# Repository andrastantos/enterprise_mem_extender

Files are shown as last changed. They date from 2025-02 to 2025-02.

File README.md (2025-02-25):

A 512kB RAM expansion design for the Enterprise computer
===================================================================

This design can be used to add up to 512kB of RAM without to an Enterprise computer.
Jumpers can be used to determine the amount of RAM added (64k, 128k, 256k or 512k).

You can read up on whole project in detail here: https://www.modularcircuits.com/blog/2025/02/25/enterprise-128-a-blast-from-the-past/

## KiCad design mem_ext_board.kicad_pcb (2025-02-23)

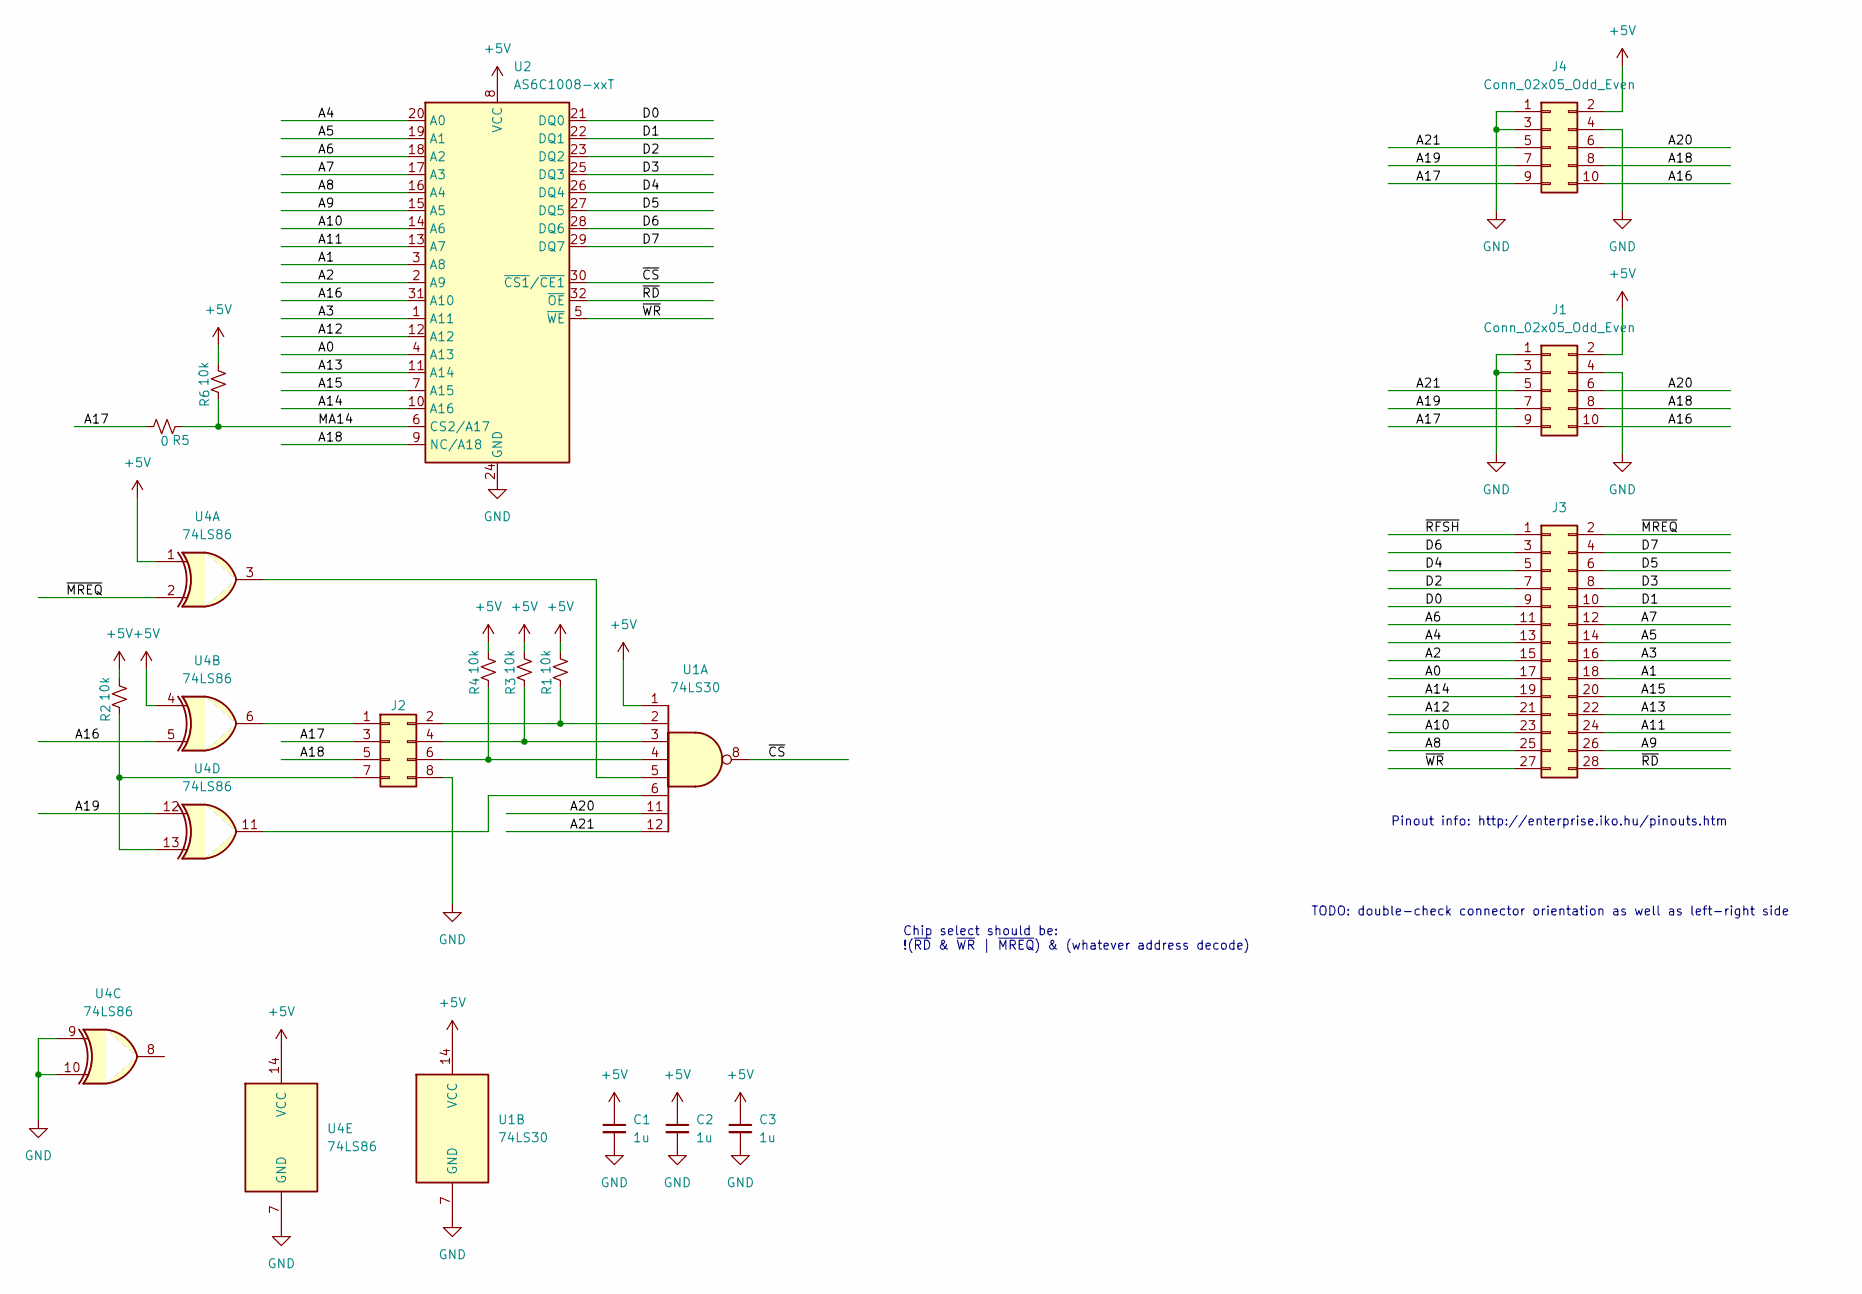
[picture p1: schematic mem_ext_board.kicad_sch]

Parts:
C1, C2, C3: 1u; C_0603_1608Metric_Pad1.08x0.95mm_HandSolder
J1: Conn_02x05_Odd_Even; PinHeader_2x05_P2.54mm_Vertical
J2: Conn_02x02_Odd_Even; PinHeader_2x04_P2.54mm_Vertical
J3: Conn_02x16_Row_Letter_First; PinSocket_2x14_P2.54mm_Vertical
J4: Conn_02x05_Odd_Even; PinSocket_2x05_P2.54mm_Vertical
R1, R2, R3, R4, R6: 10k; R_0603_1608Metric_Pad0.98x0.95mm_HandSolder
R5: 0; R_0603_1608Metric_Pad0.98x0.95mm_HandSolder
U1: 74LS30; SO-14_3.9x8.65mm_P1.27mm; mpn CD74HCT30M
U2: AS6C1008-xxT; TSOP-I-32_11-18.4x8mm_P0.5mm
U4: 74LS86; SO-14_3.9x8.65mm_P1.27mm; mpn CD74HCT86D

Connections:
+5V: C1.1, C2.1, C3.1, J1.2, J4.2, R1.1, R2.1, R3.1, R4.1, R6.1, U1.1, U1.14 (VCC), U2.8 (VCC), U4.1, U4.4, U4.14 (VCC)
/A0: J3.17, U2.4 (A13)
/A1: J3.18, U2.3 (A8)
/A2: J3.15, U2.2 (A9)
/A3: J3.16, U2.1 (A11)
/A4: J3.13, U2.20 (A0)
/A5: J3.14, U2.19 (A1)
/A6: J3.11, U2.18 (A2)
/A7: J3.12, U2.17 (A3)
/A8: J3.25, U2.16 (A4)
/A9: J3.26, U2.15 (A5)
/A10: J3.23, U2.14 (A6)
/A11: J3.24, U2.13 (A7)
/A12: J3.21, U2.12 (A12)
/A13: J3.22, U2.11 (A14)
/A14: J3.19, U2.10 (A16)
/A15: J3.20, U2.7 (A15)
/A16: J1.10, J4.10, U2.31 (A10), U4.5
/A17: J1.9, J2.3, J4.9, R5.1
/A18: J1.8, J2.5, J4.8, U2.9 (NC/A18)
/A19: J1.7, J4.7, U4.12
/A20: J1.6, J4.6, U1.11
/A21: J1.5, J4.5, U1.12
/D0: J3.9, U2.21 (DQ0)
/D1: J3.10, U2.22 (DQ1)
/D2: J3.7, U2.23 (DQ2)
/D3: J3.8, U2.25 (DQ3)
/D4: J3.5, U2.26 (DQ4)
/D5: J3.6, U2.27 (DQ5)
/D6: J3.3, U2.28 (DQ6)
/D7: J3.4, U2.29 (DQ7)
/MA14: R5.2, R6.2, U2.6 (CS2/A17)
/~CS: U1.8, U2.30 (~CS1/~CE1)
/~MREQ: J3.2, U4.2
/~RD: J3.28, U2.32 (~OE)
/~RFSH: J3.1
/~WR: J3.27, U2.5 (~WE)
GND: C1.2, C2.2, C3.2, J1.1, J1.3, J1.4, J2.8, J4.1, J4.3, J4.4, U1.7 (GND), U2.24 (GND), U4.7 (GND), U4.9, U4.10
unnamed: J2.1, U4.6
unnamed: J2.2, R1.2, U1.2
unnamed: J2.4, R3.2, U1.3
unnamed: J2.6, R4.2, U1.4
unnamed: J2.7, R2.2, U4.13
unnamed: U1.5, U4.3
unnamed: U1.6, U4.11

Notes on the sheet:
TODO: double-check connector orientation as well as left-right side
Pinout info: http://enterprise.iko.hu/pinouts.htm
Chip select should be: !(~{RD} & ~{WR} | ~{MREQ}) & (whatever address decode)

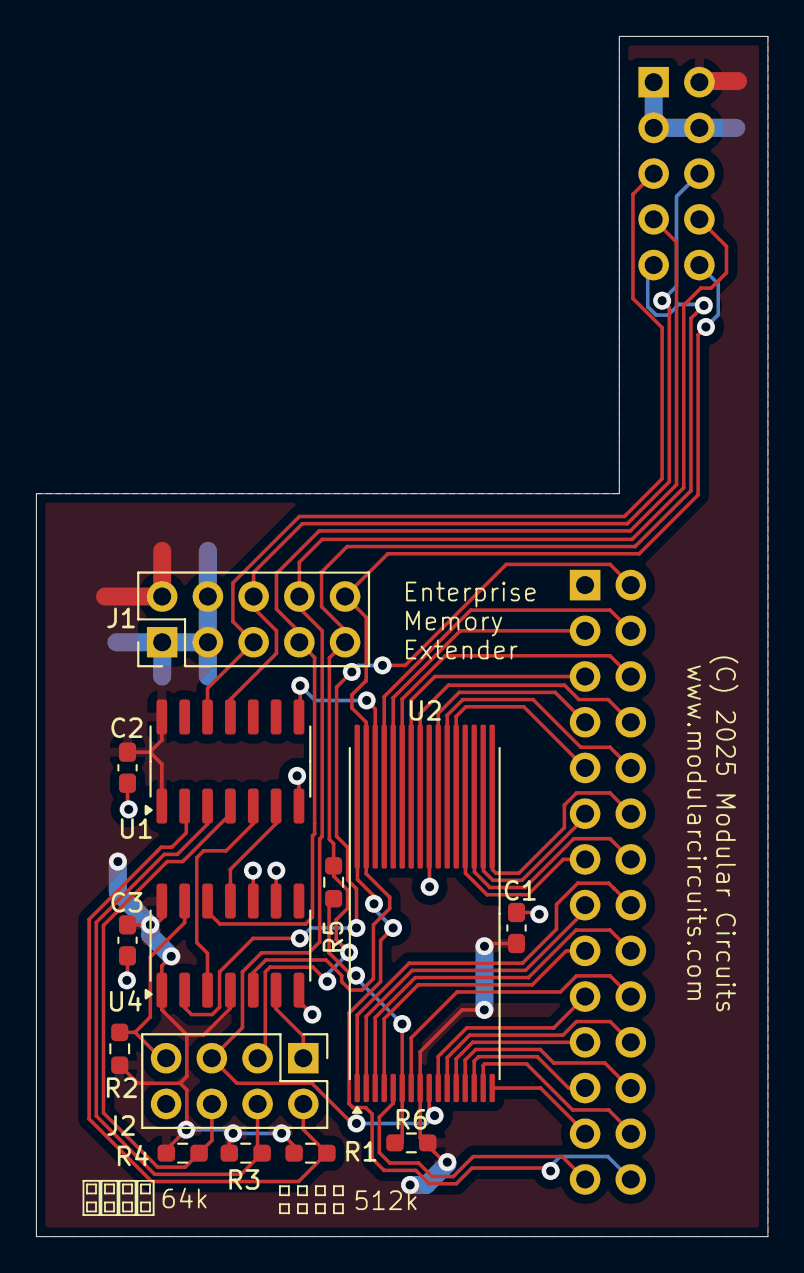
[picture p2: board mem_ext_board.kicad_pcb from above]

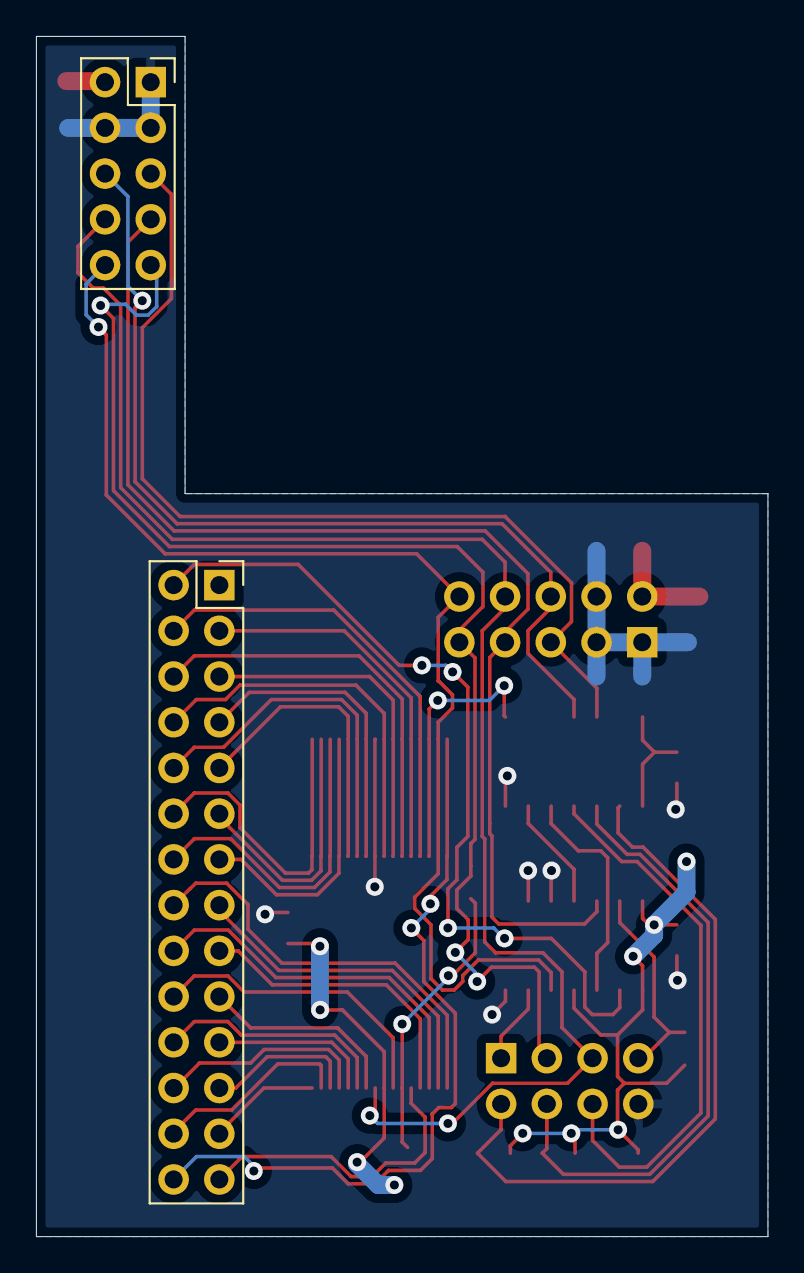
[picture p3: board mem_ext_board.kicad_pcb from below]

Board: 2 copper layers, 40.6 x 66.7 mm, 16 parts (2 on the bottom side), 44 nets.

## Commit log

2025-02-03 Updated board to hopefully final shape
    [mem_ext_board.kicad_pcb, mem_ext_board.kicad_sch]
2025-02-06 Moved connector to match mainboard layout.
    [mem_ext_board.kicad_pcb]
2025-02-06 Added support for 1Mbit part, release package added.
    [mem_ext_board-B_Cu.gbr, mem_ext_board-B_Mask.gbr, mem_ext_board-Edge_Cuts.gbr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]
2025-02-10 Universal memory footprint added: multiple package sizes are supported.
    [mem_ext_board-B_Cu.gbr, mem_ext_board-B_Mask.gbr, mem_ext_board-Edge_Cuts.gbr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]
2025-02-23 Flipped jumper setting so that operation matches silk-screen.
    [mem_ext_board.kicad_pcb, mem_ext_board.kicad_sch]

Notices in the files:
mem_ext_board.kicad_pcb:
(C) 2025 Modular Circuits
